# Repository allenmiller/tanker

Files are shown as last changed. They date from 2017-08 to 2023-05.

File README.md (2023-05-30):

# Set up Raspberry Pi

<https://www.raspberrypi.org/documentation/configuration/wireless/headless.md>

## Install Raspbian

1. Download and Install the Raspberry Pi Imager (currently v1.7.5)
2. Insert blank micro-SD card
3. Run RPI Imager
4. Select "Raspberry Pi OS Lite (32-bit)"
5. Choose SD card
6. Use the "Advanced" menu to configure hostname, username, password, WIFI network, time zone, and SSH key.
7. Click "Write"

  Unmount/eject /Volumes/bootfs

  remove microSD card from mac, insert in Raspberry Pi, power up.
  May need to port scan to find IP address

```bash
  sudo nmap -sP 10.0.0.0/24
  
  Starting Nmap 7.40 ( https://nmap.org ) at 2017-09-07 20:42 PDT
  Nmap scan report for 10.0.0.1
  Host is up (0.014s latency).
  MAC Address: CC:03:FA:7A:5B:23 (Technicolor CH USA)
...
  Nmap scan report for 10.0.0.8
  Host is up (0.015s latency).
  MAC Address: B8:27:EB:39:F7:33 (Raspberry Pi Foundation)
...
  Nmap done: 256 IP addresses (10 hosts up) scanned in 5.29 seconds
  
  ssh <username>@<IP> 
  passwd <password configured earlier>
```

```bash
sudo apt install emacs-nox tmux git
cd .ssh
emacs authorized_keys
  <copy your public key>
chmod 644 authorized_keys
```
TODO: what happened to wiringpi?  Do I need it

```bash
ssh tanker@<ip>
<Use raspi-config -> Boot Options -> Console to disable auto login of pi user.>
sudo pkill -u pi
sudo deluser -remove-home pi
sudo apt update
sudo apt full-upgrade
sudo emacs /etc/ssh/sshd_config
```

There are three lines that need to be changed to no, if they are not set that way already:

```text
ChallengeResponseAuthentication no
PasswordAuthentication no
UsePAM no
```

```bash
sudo service ssh reload
```

https://www.raspberrypi.org/documentation/configuration/security.md

raspi-config enable I2C driver.

Update node.js.  Need to pay attention to processor architecture 'uname -m'
````

curl -L <https://git.io/n-install> | bash

tanker@tortoise:~ $ node -v
v10.24.1
tanker@tortoise:~ $ npm --version
6.14.12
````

download tanker source

````bash
mkdir -p git/github.com/allenmiller
cd $_
````

Generate SSH key pair, upload public key to github
Add following to ~/.ssh/config

````text
host github.com
  Hostname github.com
  IdentityFile ~/.ssh/<private key file name>
  User git
````

Configure and clone the repo

````bash
git config --global pull.rebase true
git config --global user.email al.miller@ajmiller.net
git config --global user.name "Allen Miller"
git clone git@github.com:allenmiller/tanker.git
cd tanker/tanker
npm install
````

If "Could not find the bindings file."
Try; npm install node-gyp -- didn't happen in feb 2022

Configure gpio ports for Pump monitor

```bash
#NB: gpio command has been deprecated
#gpio mode 24 in # Sand filter pump, physical pin 35
#gpio mode 25 in # Septic tank pump, physical pin 37

# see https://raspberry-projects.com/pi/command-line/io-pins-command-line/io-pin-control-from-the-command-line

echo "24" > /sys/class/gpio/export
echo "in" > /sys/class/gpio/gpio24/direction

echo "25" > /sys/class/gpio/export
echo "in" > /sys/class/gpio/gpio25/direction
```

Install tanker

```bash
sudo cp tanker.service /lib/systemd/system/
sudo systemctl enable tanker
sudo systemctl start tanker
```

npm install tanker  # someday

i2c clock stretching bug:
````
<https://github.com/fivdi/i2c-bus/issues/36>

The default baudrate on the raspberry Pi is 100000. It can be lowered to 10000 by adding the following line to /boot/config.txt and rebooting the Pi.  Maxbotix suggests a max baudrate of 50000

dtparam=i2c_baudrate=10000

````

DHCPD IPV6 error messages in /var/log/daemon.log. See https://forums.raspberrypi.com/viewtopic.php?p=1963265.   Add:

```text
interface wlan0
noipv6
```

to /etc/dhcpcd.conf, then

```bash
sudo dhcpcd --rebind wlan0
```

Raspberry Pi watchdog reset
````
<https://raspberrypi.stackexchange.com/questions/1401/how-do-i-hard-reset-a-raspberry-pi>

````

Backend web server and database manager for Tanker

````

Measurements:

Relative to ground

top of tank     62
alarm level     90
alert level    106
normal high    121
lower limit    137
bottom of tank 202

````

Pump Tank characteristics
````

Capacity     1150 gal   4353 l
Height         55  in    140 cm
Cap/Height  22 gal/in 8.67 gal/cm  30.6 l/cm

Volume consumed at lower limit: 564 gal
Volume consumed at normal high: 702 gal
Volume consumed at alarm level: 971 gal

````

Lidar detector calibration

Distance measured from bottom of enclosure in which LIDAR is mounted
````

Measured          Reported
54                  37 +/- 2
84                  64
112                 93
202                187
248                238

````
S3 -- Create new bucket tanker.ajmiller.net
Enable web hosting
S3 Bucket Policy
````

{
    "Version": "2012-10-17",
    "Statement": [
        {
            "Sid": "AddPerm",
            "Effect": "Allow",
            "Principal": "*",
            "Action": "s3:GetObject",
            "Resource": "arn:aws:s3:::tanker.ajmiller.net/*"
        }
    ]
}

````
Default CORS configuration works.

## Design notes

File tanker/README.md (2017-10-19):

node read_pump_status.js SEPTIC-PUMP 25 5000
node read_pump_status.js SANDFILTER-PUMP 27 5000
while [ 1 ] ; do node read_tank_level-lidar.js 40; sleep 300;  done

gpio readall
vcgencmd measure_temp

i2c clock stretching bug

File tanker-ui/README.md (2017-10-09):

npm run build
profile=ajmiller
bucket=tanker.ajmiller.net
aws --profile ${profile} s3 sync --delete build s3://${bucket}/

Create DNS Hosted zone "tanker.ajmiller.net" in Route53,
Create CNAME graph.tanker.ajmiller.net. CNAME tanker-ui.ajmiller.net.s3.amazonaws.com

Delegate NS records for tanker.ajmiller.net in Hostway to point to R53

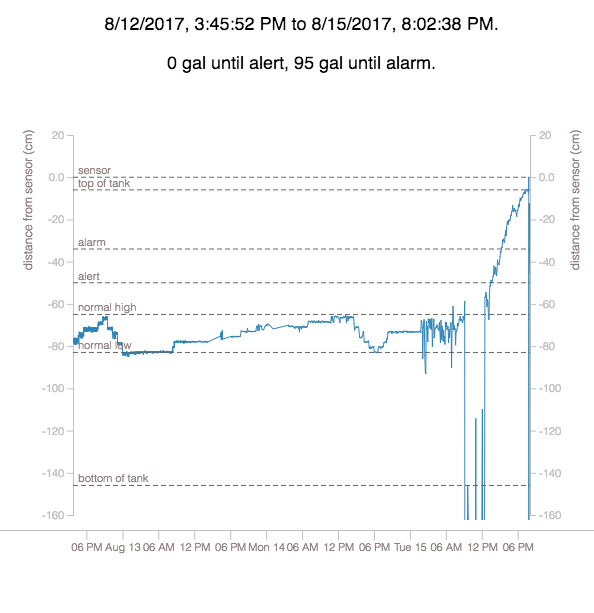
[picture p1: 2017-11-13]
doc/maxbotix-sensor-final.png

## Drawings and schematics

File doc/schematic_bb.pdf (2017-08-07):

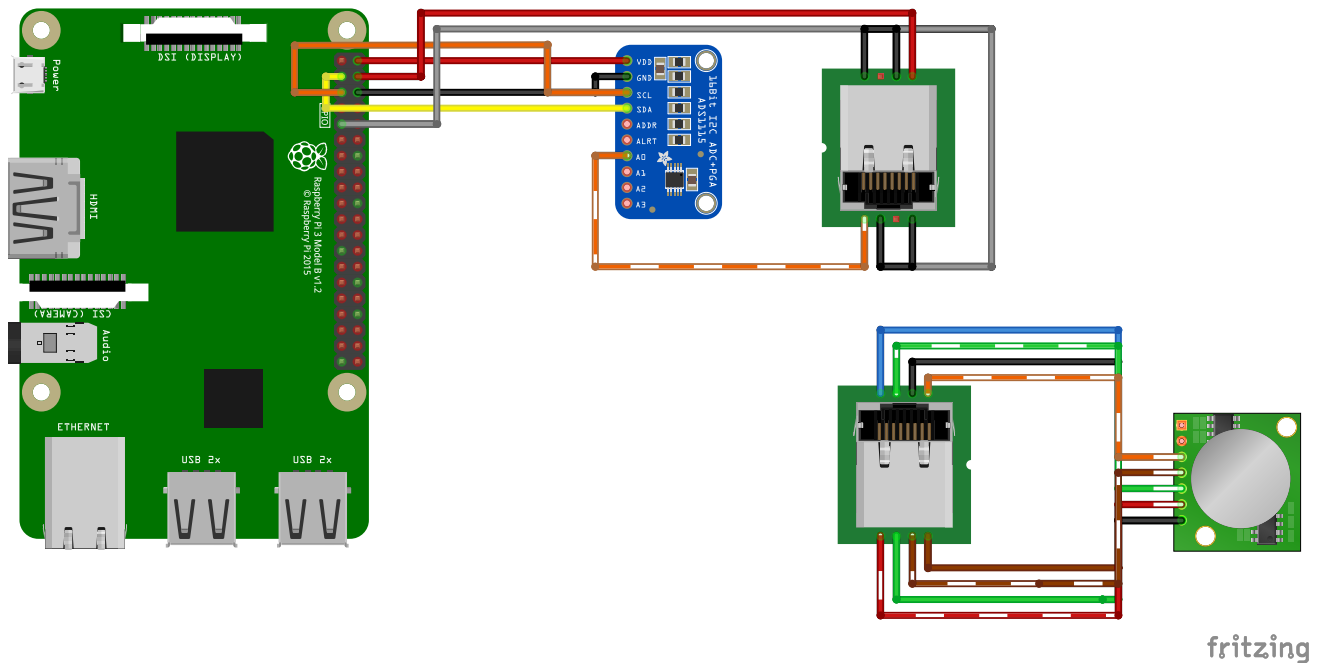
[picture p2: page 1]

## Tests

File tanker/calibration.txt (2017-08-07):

Measured distance (cm)         Raw reading       calculaded distance

208.5                              751.5           186.4
174                                678.9           168.4
134                                519.6           128.9
100                                392.4            97.3
59                                 224.8            55.8
32                                 116.7            28.9

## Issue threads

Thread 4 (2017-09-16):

read_tank_level utilities need error reporting

allenmiller, 2017-09-16:
The tank read utilities should report when there is a problem reading the sensor.  Perhaps make an entry in the dynamodb table.

1: /home/pi/git/github.com/allenmiller/tanker-backend/tanker/read_tank_level-lidar.js
2: 40
events.js:182
      throw er; // Unhandled 'error' event
      ^

Error: IOError: [Errno 121] Remote I/O error
    at PythonShell.parseError (/home/pi/git/github.com/allenmiller/tanker-backend/tanker/node_modules/python-shell/index.js:183:17)
    at terminateIfNeeded (/home/pi/git/github.com/allenmiller/tanker-backend/tanker/node_modules/python-shell/index.js:98:28)
    at ChildProcess.<anonymous> (/home/pi/git/github.com/allenmiller/tanker-backend/tanker/node_modules/python-shell/index.js:88:9)
    at emitTwo (events.js:125:13)
    at ChildProcess.emit (events.js:213:7)
    at Process.ChildProcess._handle.onexit (internal/child_process.js:200:12)
    ----- Python Traceback -----
    File "/home/pi/git/github.com/Sanderi44/Lidar-Lite/python/test.py", line 9, in <module>
      print lidar.getDistance()
    File "/home/pi/git/github.com/Sanderi44/Lidar-Lite/python/lidar_lite.py", line 33, in getDistance
      self.writeAndWait(self.distWriteReg, self.distWriteVal)
    File "/home/pi/git/github.com/Sanderi44/Lidar-Lite/python/lidar_lite.py", line 24, in writeAndWait
      self.bus.write_byte_data(self.address, register, value);

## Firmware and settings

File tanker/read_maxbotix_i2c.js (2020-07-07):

const Gpio = require('onoff').Gpio;
const i2c = require('i2c-bus')
const request = require('request');

const MINS_15_MS               = 900000;
const MINS_5_MS                = 300000;
const SECS_5_MS                = 5000;

const I2C_BUS                  = 1;
const MAXBOTIX_BUS_ADDR        = 0x70;
const MAXBOTIX_WAIT_TIME_MS    = 100;
const MEASURE_RANGE_COMMAND    = 0x51;
const READ_MEASUREMENT_ADDRESS = 0xE1;
const SENSOR_LEVEL             = 47;  // cm below ground level
const SENSOR_NAME              = "MB_7040_100";
const SENSOR_OFFSET            = 0;   // constant error in sensor position.
const SEPTIC_PUMP_PIN          = 26;  // physical pin 37
const SANDFILTER_PUMP_PIN      = 20;  // physical pin 38

const POST_URL = 'https://rmecu0chj5.execute-api.us-east-1.amazonaws.com/prod/tanker';

let readTankLevelInterval;
let septicPumpInterval;
let sandFilterPumpInterval;

function swapBytes(word) {
    return ((word & 0xff00) >> 8) | ((word & 0xff) << 8);
}

async function delay(ms) {
    return new Promise(resolve => { setTimeout(resolve, ms); });
}

async function getDistance(i2cBus) {
    //i2cset -y 1 0x70 0x51 && sleep 1 && i2cget -y 1 0x70 0xE1 w
    i2cBus.writeByteSync(MAXBOTIX_BUS_ADDR, 0, MEASURE_RANGE_COMMAND)
    await delay(MAXBOTIX_WAIT_TIME_MS)
    const rawData = i2cBus.readWordSync(MAXBOTIX_BUS_ADDR, READ_MEASUREMENT_ADDRESS);
    return swapBytes(rawData)
}

function readTankLevel(i2cBus) {
    getDistance(i2cBus)
	.then(distance => { postRecord(buildLevelRecord(distance)) })
	.catch(err => { console.log(err) })
}

function buildLevelRecord(distance) {
    let record = {};
    record.type = "LEVEL";
    record.sensor = SENSOR_NAME;
    record.sensorLevel = SENSOR_LEVEL;
    record.distance_cm = distance + SENSOR_OFFSET;
    record.time = (new Date()).getTime();
    return record;
}

function buildPumpRecord(pump) {
    let record = {};
    record.type = "PUMP_STATE";
    record.tank = pump;
    record.state = 1;
    record.time = (new Date()).getTime();
    return record;
}

function postRecord(record) {
    console.log("Posting ", record);
    request.post({
      url: POST_URL,
      json: true,
      body: record
    }, function (error, response, body) {
      if (error) {
        console.log("ERROR posting record");
        console.log(response);
        console.log(body);
        console.log("attempting to save locally");
        fs.appendFile('levels.js', body, (err) => {
          "use strict";
          if (err) throw err;
          console.log("Saved locally")
        });
          // throw error;
      }
    });
  };

function readPumpStatus(tankName, GpioPin) {
    const sensor = new Gpio(GpioPin, 'in');
    pumpState = sensor.readSync();
    if (pumpState) {
	postRecord(buildPumpRecord(tankName));
    }
    console.log("%s: %s", tankName, pumpState)
}

process.on("SIGTERM", () => {
    console.log("Shutting down");
    clearInterval(readTankLevelInterval);
    clearInterval(septicPumpInterval);
    clearInterval(sandFilterPumpInterval);
    i2cBus.closeSync();
    console.log("Cleared intervals and closed i2c bus")
})

let i2cBus = i2c.openSync(I2C_BUS);
readTankLevel(i2cBus);
readPumpStatus("SEPTIC-PUMP", SEPTIC_PUMP_PIN);
readPumpStatus("SANDFILTER-PUMP", SANDFILTER_PUMP_PIN);
readTankLevelInterval = setInterval(readTankLevel, MINS_5_MS, i2cBus);
septicPumpInterval = setInterval(readPumpStatus, SECS_5_MS, "SEPTIC-PUMP", SEPTIC_PUMP_PIN)
sandFilterPumpInterval = setInterval(readPumpStatus, SECS_5_MS, "SANDFILTER-PUMP", SANDFILTER_PUMP_PIN)

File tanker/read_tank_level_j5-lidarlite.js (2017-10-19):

let Raspi = require('raspi-io');
let five = require("johnny-five");
let board = new five.Board({
  io: new Raspi(),
  repl: false,
  debug: false
});

board.on("message", function(event) {
  /*
    Event {
      type: "info"|"warn"|"fail",
      timestamp: Time of event in milliseconds,
      class: name of relevant component class,
      message: message [+ ...detail]
    }
  */
  console.log("Received a %s message, from %s, reporting: %s", event.type, event.class, event.message);
});

board.on("ready", function () {
  console.log("board is ready");
  let proximity = new five.Proximity({
    controller: "LIDARLITE",
    freq: 10000 // 10 seconds
  });

    proximity.on("data", function() {
		console.log(this.cm, ' cm');
    });

//  proximity.on("change", function () {
//    console.log(this.cm + "cm");
//  });

});

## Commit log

2017-08-06 add fritzing schematic
    [schematic.fzz]
2017-08-07 manual calibration test
2017-08-07 update schematic
    [schematic.fzz]
2017-08-07 update fritzing docs
    [schematic.fzz]
2017-08-07 add schematic pdf
2017-08-13 add y axis on rhs
2017-08-13 measure physical distances from sensor
2017-08-23 start work on module to read from LIDAR
2017-08-23 implement reading from lidar sensor
2017-08-23 update POST for lidar sensor
2017-08-28 offset measured distance by sensor level
2017-08-28 UI adjustments to reflect measuring relative to ground level
2017-09-04 update schematic for RPI 0W and LIDAR
    [schematic.fzz]
2017-09-08 raspberry pi setup notes
2017-09-16 Adjust sensor position
2017-09-16 start utility to read pump status
2017-09-17 work on gpio pin reading
2017-09-17 flesh out pump reporting logic
2017-09-18 implement POST for pump state
2017-09-21 display tank pump data
2017-09-21 tweak y axis height
2017-09-23 add sensor offset
2017-09-24 print tank name and pin
2017-09-26 Accomodate a second pump
2017-09-26 UI work: humanize time, recalculate capacities on tracker change.
2017-10-08 adjust gal/cm tank capacity based on county documentation
2017-10-14 raise alert level by 10cm
2017-11-13 Add last screenshot of results using failed maxbotix untrasonic sensor
2018-11-19 update schematic, play with gcp
    [schematic.fzz]
2018-12-02 maxbotix i2cxl datasheet
2020-06-14 Doc for connecting MaxBotix sensor to RPI I2C
2020-06-15 Experiment with MaxBotix MB7040-100 I2C
    [boot-config.txt]
2020-06-15 Update README for i2c-bus
2020-06-15 Node.js program for reading distance from MaxBotix I2C
2020-07-07 Maxbotix I2C support (#10)
    * Support for MaxBotix I2C-based sensor
    * reduce dependencies to only those needed by maxbotix i2c
    * update readme
    * read a gpio ping
    * experiment with onoff package
    * add pump status pins
    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
2021-06-02 Bump dot-prop from 4.2.0 to 4.2.1 in /tanker-ui
    Bumps [dot-prop](https://github.com/sindresorhus/dot-prop) from 4.2.0 to 4.2.1.
    - [Release notes](https://github.com/sindresorhus/dot-prop/releases)
    - [Commits](https://github.com/sindresorhus/dot-prop/compare/v4.2.0...v4.2.1)
